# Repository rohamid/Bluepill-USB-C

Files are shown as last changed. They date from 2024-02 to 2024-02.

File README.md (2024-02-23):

# STM32F103 Bluepill USB C #
STM32F103 Bluepill PCB with USB C and castellated PCB.

## Warning ##
After finished and ordering from `JLCPCB` I spotted a mistake that I swapped USB D- with D+ and vice versa.

## Problem fixed ##
* [ ] Fixing swapped D- D+ USB trace

## Bluepill USB C PCB ##
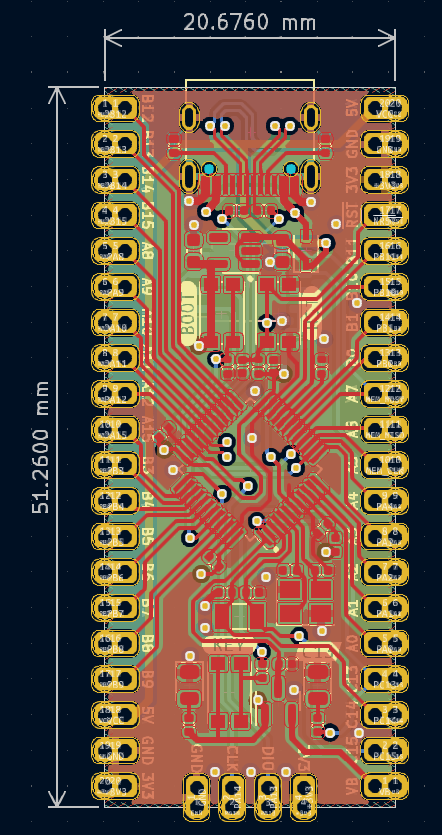
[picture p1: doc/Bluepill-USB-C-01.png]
Bluepill USB C


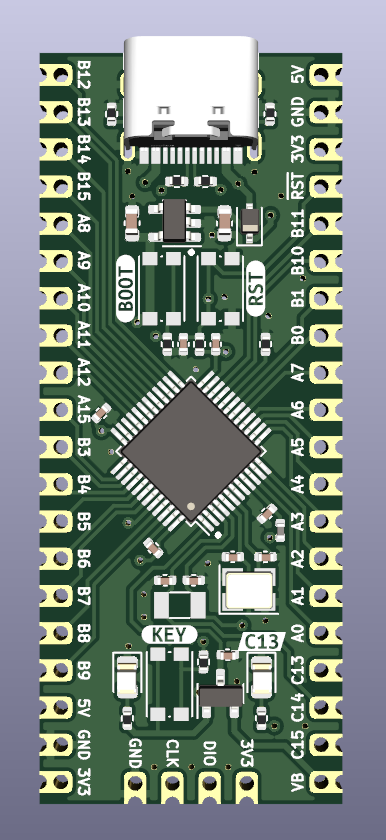
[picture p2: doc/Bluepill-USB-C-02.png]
Bluepill USB C


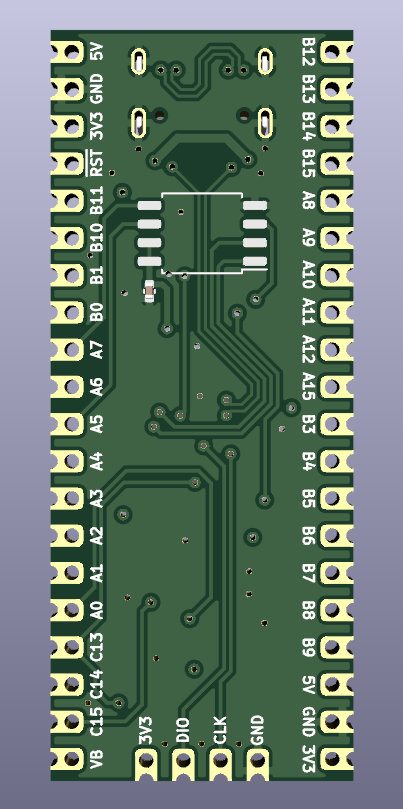
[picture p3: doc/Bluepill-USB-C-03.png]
Bluepill USB C


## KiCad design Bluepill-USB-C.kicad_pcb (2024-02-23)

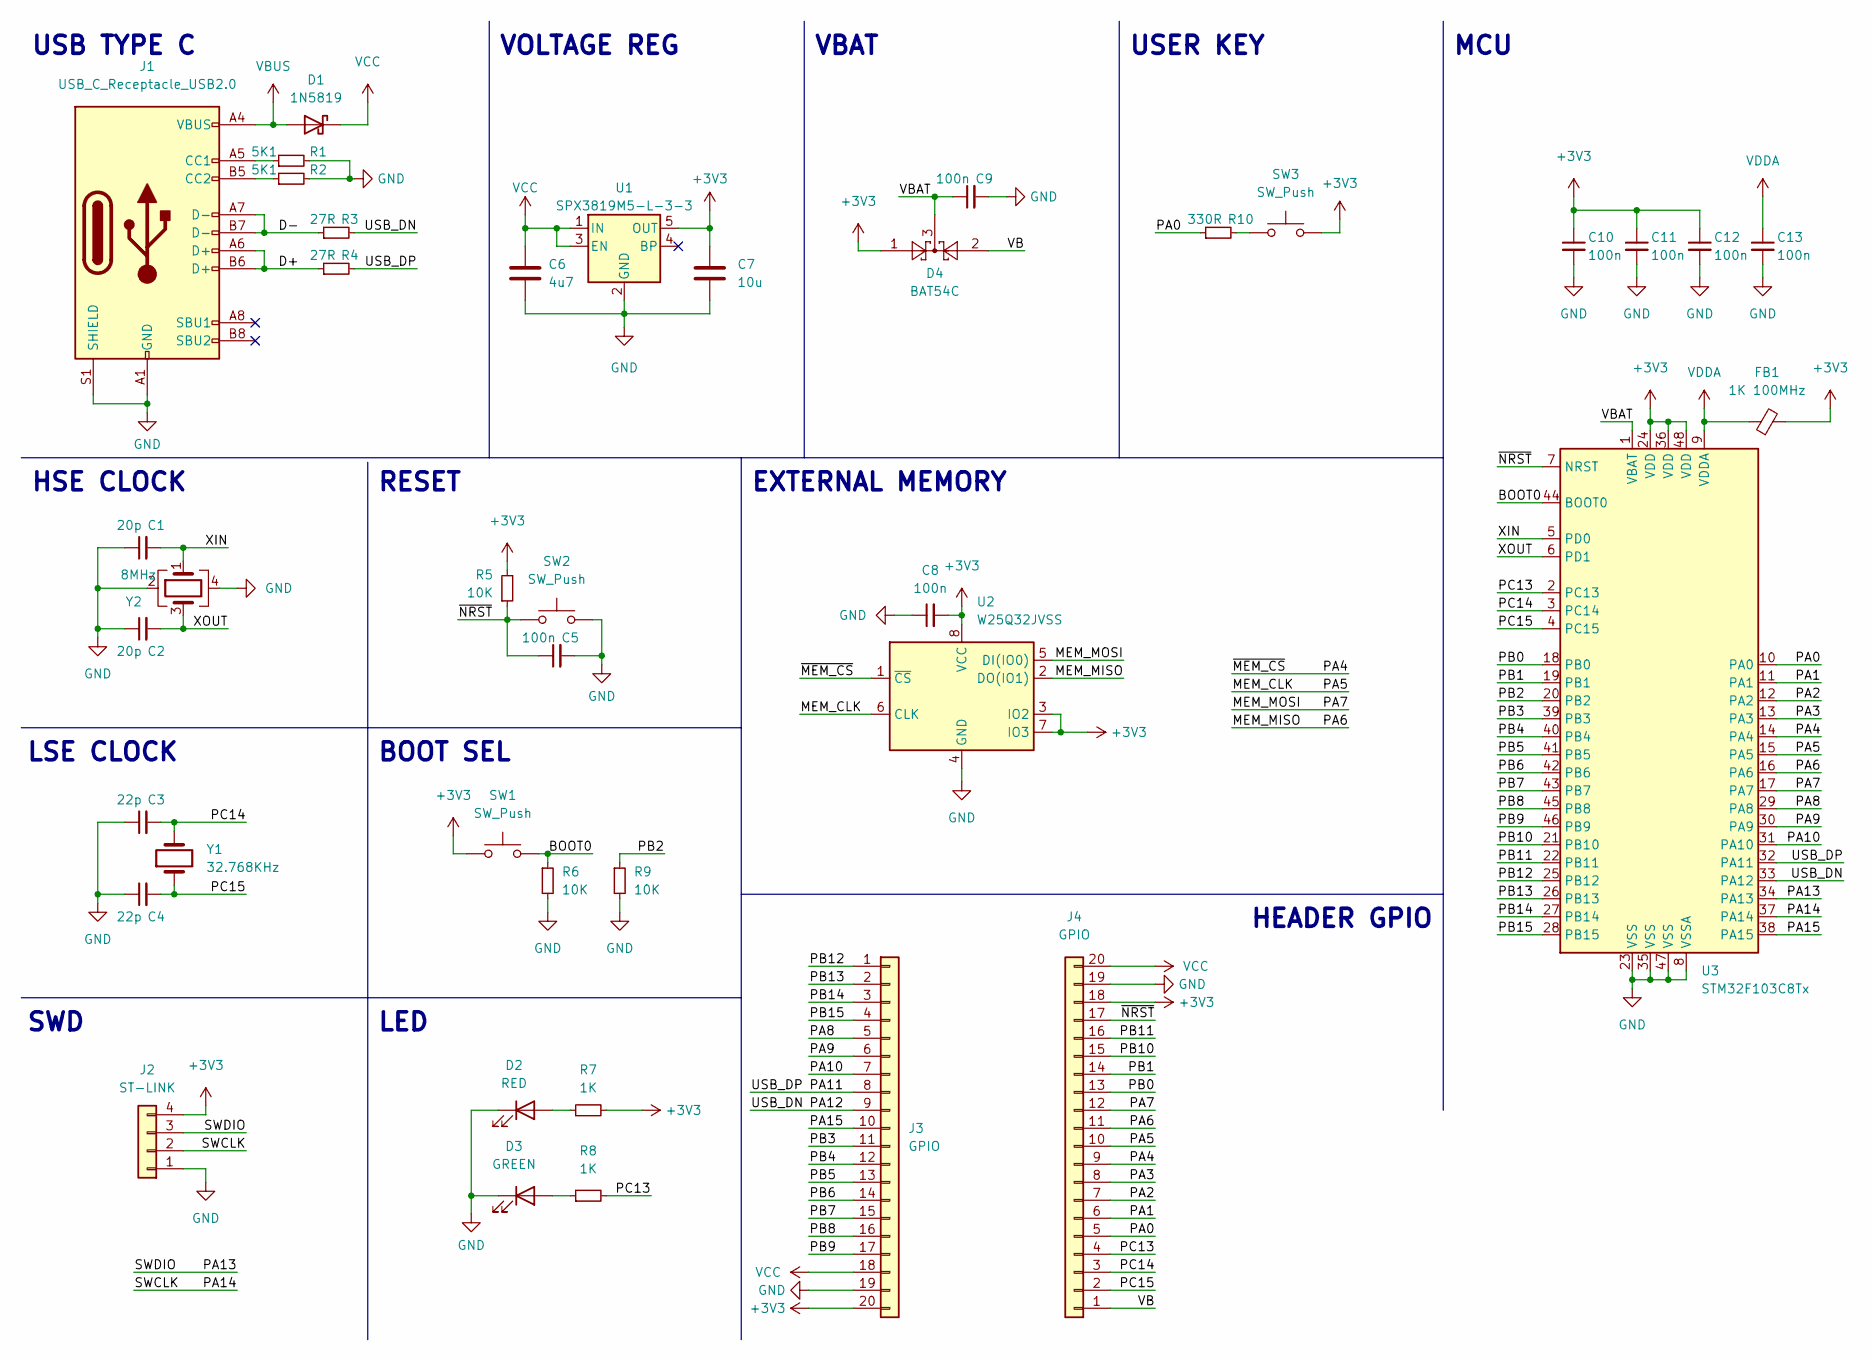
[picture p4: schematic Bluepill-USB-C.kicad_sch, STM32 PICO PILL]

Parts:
C1, C2: 20p; C_0402_1005Metric; LCSC Part Number C1554
C3, C4: 22p; C_0402_1005Metric; LCSC Part Number C1555
C5, C8, C9, C10, C11, C12, C13: 100n; C_0402_1005Metric; LCSC Part Number C307331
C6: 4u7; C_0603_1608Metric; LCSC Part Number C19666
C7: 10u; C_0603_1608Metric; LCSC Part Number C19702
D1: 1N5819; D_SOD-323; LCSC Part Number C191023
D2: RED; LED_0805_2012Metric; LCSC Part Number C84256
D3: GREEN; LED_0805_2012Metric; LCSC Part Number C34499
D4: BAT54C; SOT-23; LCSC Part Number C37704
FB1: 1K 100MHz; L_0402_1005Metric; LCSC Part Number C76884
J1: USB_C_Receptacle_USB2.0; USB_C_Receptacle_G-Switch_GT-USB-7010ASV
J2: ST-LINK; castellated_header_4p
J3, J4: GPIO; castellated_20p
R1, R2: 5K1; R_0402_1005Metric; LCSC Part Number C25905
R3, R4: 27R; R_0402_1005Metric; LCSC Part Number C25092
R5, R6, R9: 10K; R_0402_1005Metric; LCSC Part Number C25744
R7, R8: 1K; R_0402_1005Metric; LCSC Part Number C11702
R10: 330R; R_0402_1005Metric; LCSC Part Number C25104
SW1, SW2, SW3: SW_Push; SW_Push_1P1T_NO_CK_KMR2; LCSC Part Number C127488
U1: SPX3819M5-L-3-3; SOT-23-5; LCSC Part Number C9055
U2: W25Q32JVSS; SOIC-8_5.23x5.23mm_P1.27mm; LCSC Part Number C97521
U3: STM32F103C8Tx; LQFP-48_7x7mm_P0.5mm; LCSC Part Number C8734
Y1: 32.768KHz; Crystal_SMD_3215-2Pin_3.2x1.5mm; LCSC Part Number C93232
Y2: 8MHz; Crystal_SMD_3225-4Pin_3.2x2.5mm; LCSC Part Number C253723

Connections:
+3V3: C7.1, C8.2, C10.1, C11.1, C12.1, D4.1, FB1.2, J2.4, J3.20, J4.18, R5.2, R7.2, SW1.1, SW3.2, U1.5 (OUT), U2.3 (IO2), U2.7 (IO3), U2.8 (VCC), U3.24 (VDD), U3.36 (VDD), U3.48 (VDD)
/BOOT0: R6.1, SW1.2, U3.44 (BOOT0)
/D+: J1.A6 (D+), J1.B6 (D+), R4.1
/D-: J1.A7 (D-), J1.B7 (D-), R3.1
/MEM_CLK: J4.10, U2.6 (CLK), U3.15 (PA5)
/MEM_MISO: J4.11, U2.2 (DO(IO1)), U3.16 (PA6)
/MEM_MOSI: J4.12, U2.5 (DI(IO0)), U3.17 (PA7)
/PA0: J4.5, R10.1, U3.10 (PA0)
/PA1: J4.6, U3.11 (PA1)
/PA2: J4.7, U3.12 (PA2)
/PA3: J4.8, U3.13 (PA3)
/PA4: J4.9, U2.1 (~CS), U3.14 (PA4)
/PA8: J3.5, U3.29 (PA8)
/PA9: J3.6, U3.30 (PA9)
/PA10: J3.7, U3.31 (PA10)
/PA11: J3.8, R4.2, U3.32 (PA11)
/PA12: J3.9, R3.2, U3.33 (PA12)
/PA13: J2.3, U3.34 (PA13)
/PA14: J2.2, U3.37 (PA14)
/PA15: J3.10, U3.38 (PA15)
/PB0: J4.13, U3.18 (PB0)
/PB1: J4.14, U3.19 (PB1)
/PB2: R9.1, U3.20 (PB2)
/PB3: J3.11, U3.39 (PB3)
/PB4: J3.12, U3.40 (PB4)
/PB5: J3.13, U3.41 (PB5)
/PB6: J3.14, U3.42 (PB6)
/PB7: J3.15, U3.43 (PB7)
/PB8: J3.16, U3.45 (PB8)
/PB9: J3.17, U3.46 (PB9)
/PB10: J4.15, U3.21 (PB10)
/PB11: J4.16, U3.22 (PB11)
/PB12: J3.1, U3.25 (PB12)
/PB13: J3.2, U3.26 (PB13)
/PB14: J3.3, U3.27 (PB14)
/PB15: J3.4, U3.28 (PB15)
/PC13: J4.4, R8.2, U3.2 (PC13)
/PC14: C3.2, J4.3, U3.3 (PC14), Y1.2
/PC15: C4.2, J4.2, U3.4 (PC15), Y1.1
/VB: D4.2, J4.1
/VBAT: C9.1, D4.3, U3.1 (VBAT)
/XIN: C1.2, U3.5 (PD0), Y2.1
/XOUT: C2.2, U3.6 (PD1), Y2.3
/~NRST: C5.1, J4.17, R5.1, SW2.1, U3.7 (NRST)
GND: C1.1, C2.1, C3.1, C4.1, C5.2, C6.2, C7.2, C8.1, C9.2, C10.2, C11.2, C12.2, C13.2, D2.1 (K), D3.1 (K), J1.A1 (GND), J1.A12 (GND), J1.B1 (GND), J1.B12 (GND), J1.S1 (SHIELD), J2.1, J3.19, J4.19, R1.2, R2.2, R6.2, R9.2, SW2.2, U1.2 (GND), U2.4 (GND), U3.8 (VSSA), U3.23 (VSS), U3.35 (VSS), U3.47 (VSS), Y2.2, Y2.4
unnamed: D2.2 (A), R7.1
unnamed: D3.2 (A), R8.1
unnamed: J1.A5 (CC1), R1.1
unnamed: J1.B5 (CC2), R2.1
unnamed: R10.2, SW3.1
VBUS: D1.2 (A), J1.A4 (VBUS), J1.A9 (VBUS), J1.B4 (VBUS), J1.B9 (VBUS)
VCC: C6.1, D1.1 (K), J3.18, J4.20, U1.1 (IN), U1.3 (EN)
VDDA: C13.1, FB1.1, U3.9 (VDDA)

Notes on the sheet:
MCU
RESET
BOOT SEL
HEADER GPIO
EXTERNAL MEMORY
VOLTAGE REG
VBAT
SWD
USB TYPE C
LED
HSE CLOCK
USER KEY
LSE CLOCK

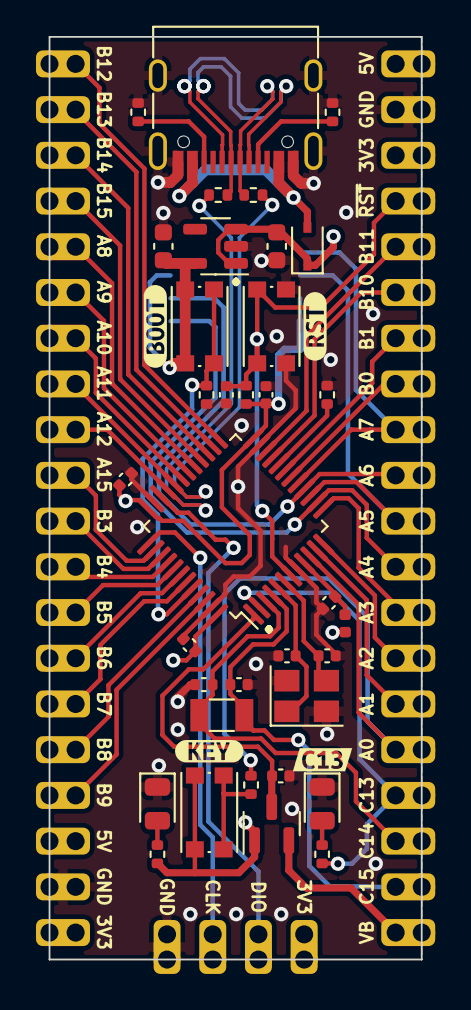
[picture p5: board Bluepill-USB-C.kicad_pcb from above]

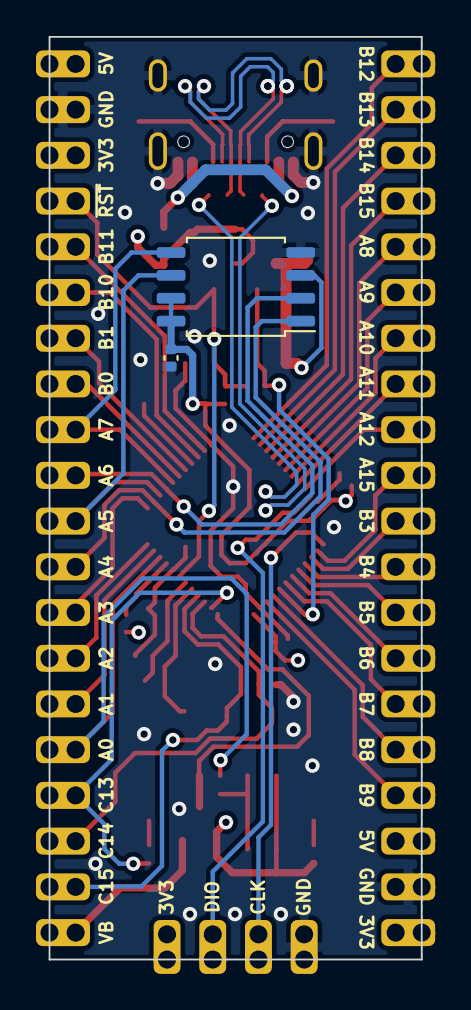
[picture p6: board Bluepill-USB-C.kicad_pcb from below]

Board: 4 copper layers, 20.7 x 51.3 mm, 44 parts (2 on the bottom side), 53 nets.

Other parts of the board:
kibuzzard-63FDC3E6: G***; kibuzzard-63FDC3E6
kibuzzard-63FDC36C: G***; kibuzzard-63FDC36C
kibuzzard-63FDC37C: G***; kibuzzard-63FDC37C
kibuzzard-63FDCD3E: G***; kibuzzard-63FDCD3E
